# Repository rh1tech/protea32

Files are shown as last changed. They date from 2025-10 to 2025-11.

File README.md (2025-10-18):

# Protea

Protea is an open-source, feature-rich serial terminal and Wi-Fi modem PCB, designed in KiCad and released under the GNU General Public License (version 3 or later). Inspired by David Hansel's](https://github.com/dhansel) [VersaTerm](https://github.com/dhansel/VersaTerm) and [Richard Bettridge's](https://richardbettridge.com/) [RS232 Serial Wi-Fi Modem](https://github.com/TheOldNet/vintage-computer-wifi-modem), Protea combines modern connectivity with classic terminal functionality.

## Key Features

* **Plug-and-Play Operation**: simply connect a standard USB keyboard and an HDMI display—no additional host system or software required. Protea powers on instantly, requiring no boot-up sequence or shutdown procedure.
* **Universal Serial I/O**. Supports both RS232 and TTL (3.3 V or 5 V) serial levels. Choose from fixed presets or any custom baud rate between 50 and 921 600 baud. Full hardware (RTS/CTS) and software (XOn/XOff) flow control ensure reliable data transfer.
* **Comprehensive VT100 Emulation**. Full support for VT100 attributes—including bold, underline, blink, inverse, double width, and double height—and 16 ANSI colors. Advanced control-sequence compatibility passes VTTest for VT52/VT100/VT102 conformance.
* **PETSCII Mode**. Emulates the PETSCII character set and control codes used by the Commodore 64, complete with an authentic PETSCII bitmap font.
* **RP2040-Powered**. Built around the Raspberry Pi RP2040 microcontroller, Protea delivers instant-on performance and robust processing for terminal emulation.
* **Built-In Wi-Fi Modem**. Integrates an ESP8266EX module with on-board antenna, providing transparent serial-to-Wi-Fi bridging for telnet, web-based interfaces, or custom network protocols. Enables remote terminal sessions over local networks or the Internet.
* **Highly Configurable**. Customizable color palettes, and savable configuration profiles mean you can tailor Protea to any workflow. A built-in menu system allows on-the-fly adjustments without recompiling firmware.

Protea brings together the convenience of modern hardware with the nostalgia and versatility of vintage terminal interfaces—ideal for hobbyists, retro-computing enthusiasts, and embedded systems developers.

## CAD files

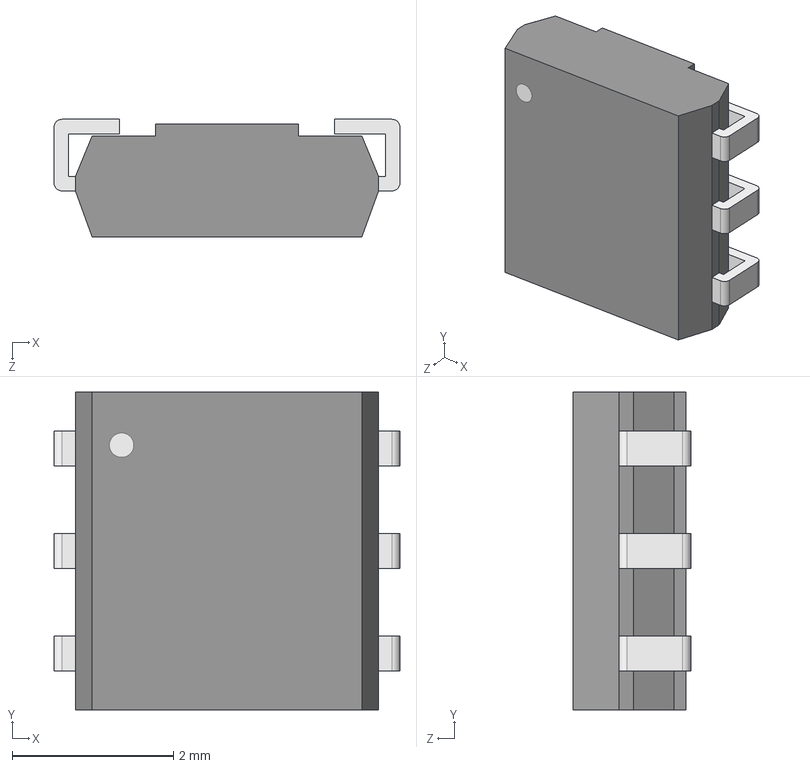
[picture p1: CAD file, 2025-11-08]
3D/DS2401P+.stp
4.29 x 3.94 x 1.46 mm

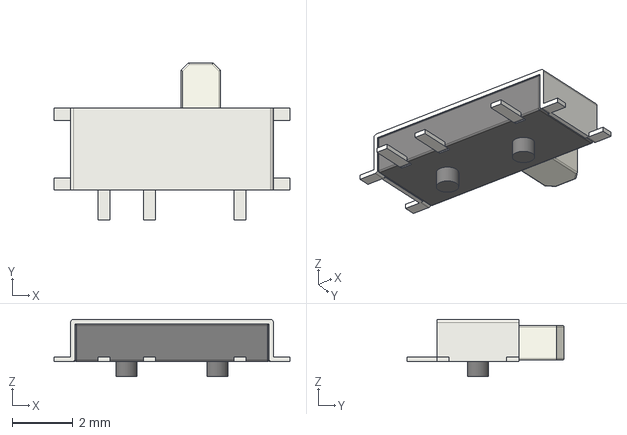
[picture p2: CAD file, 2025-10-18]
3D/SW_MSK12C02.step
7.80 x 5.20 x 1.90 mm

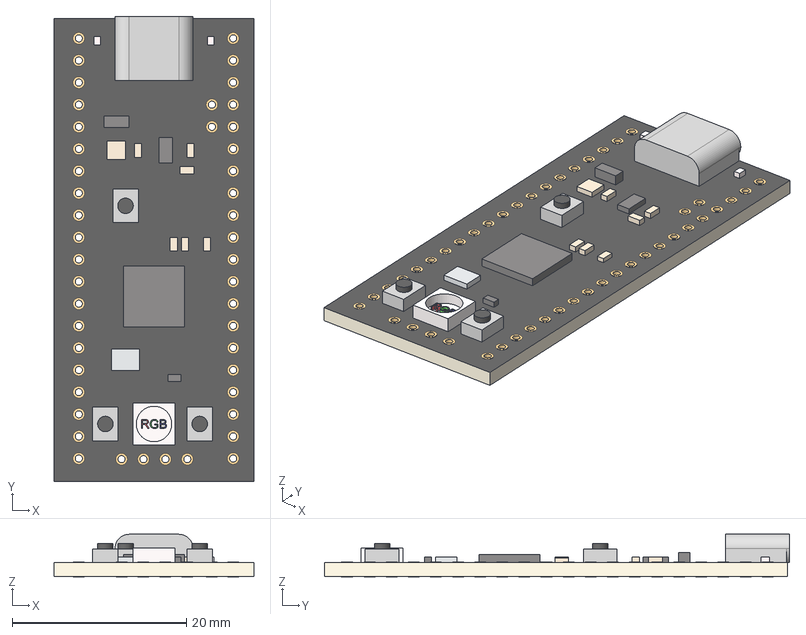
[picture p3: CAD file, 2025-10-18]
3D/PICO Clone-Black .step
22.9 x 53.3 x 4.88 mm

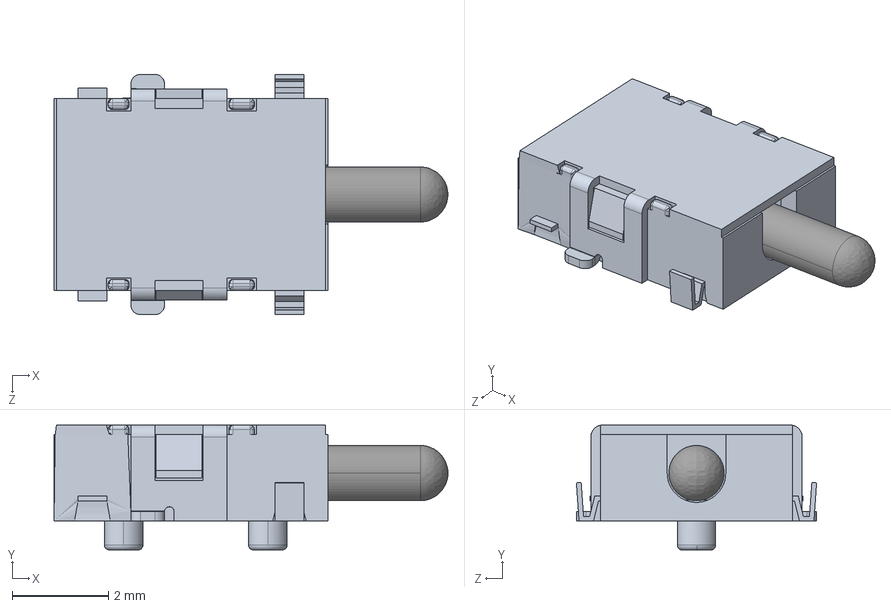
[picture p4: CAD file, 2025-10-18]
3D/SDS001R.stp
8.20 x 2.60 x 5.00 mm
SDS001R_PART1_1
SDS001R_PART2_3
SDS001R_PART2_2

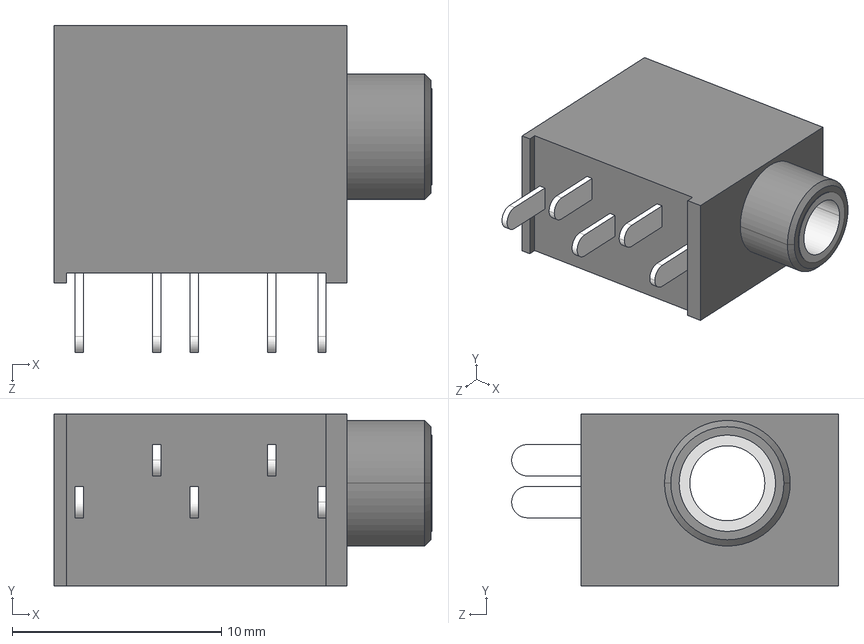
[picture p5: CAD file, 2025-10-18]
3D/SJ1-3535NG.stp
18.1 x 8.20 x 15.6 mm

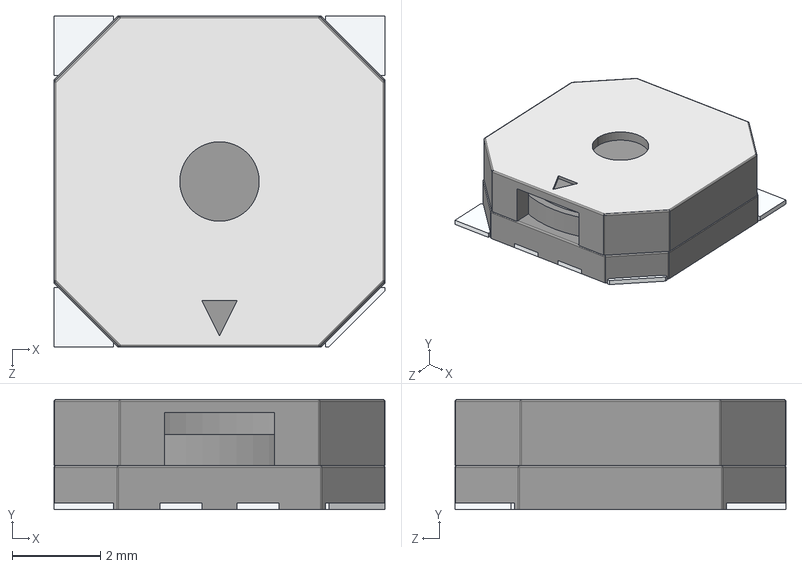
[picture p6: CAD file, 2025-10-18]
3D/CMT-7525-80-SMT-TR.stp
7.50 x 2.50 x 7.50 mm

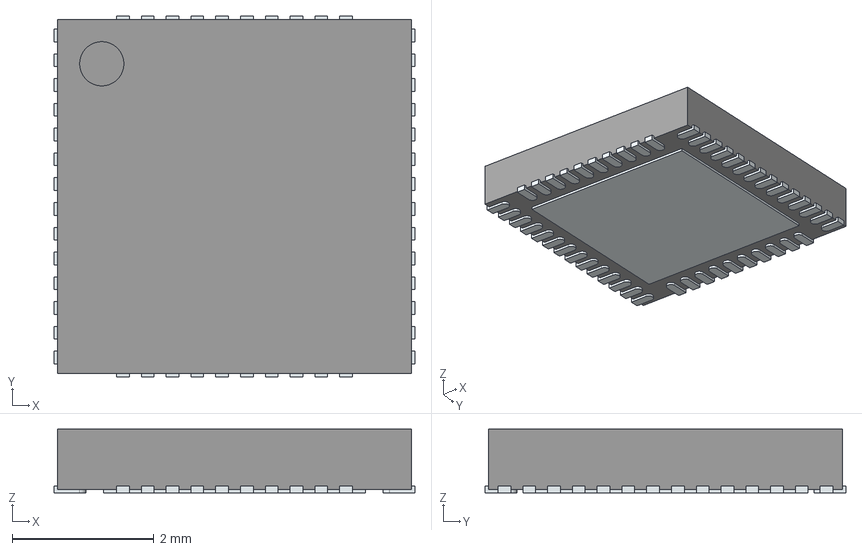
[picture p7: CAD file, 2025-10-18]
3D/ESP32-D0WD-V3.stp
5.10 x 5.10 x 0.9 mm
ThermalPin
PinsArrayLR
PinsArrayTB

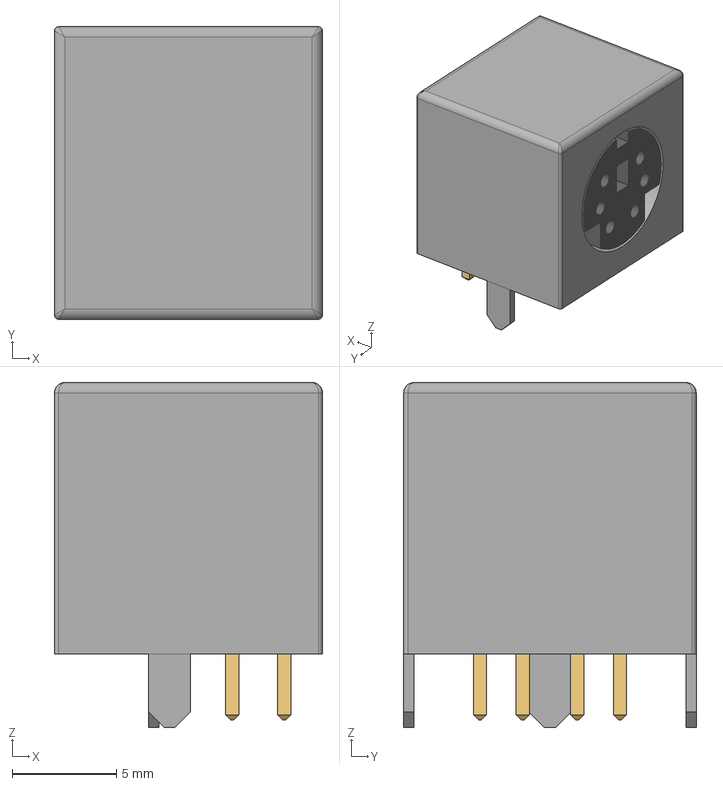
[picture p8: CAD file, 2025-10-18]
3D/Mini-DIN-6P.step
12.8 x 14.0 x 16.5 mm

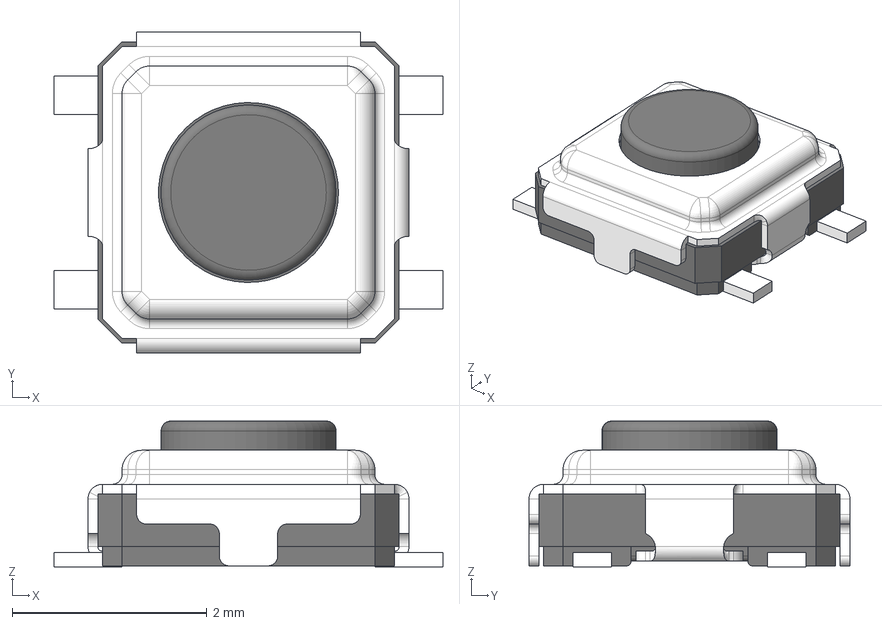
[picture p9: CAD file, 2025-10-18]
3D/Ts-1233_1.5.stp
4.00 x 3.30 x 1.50 mm

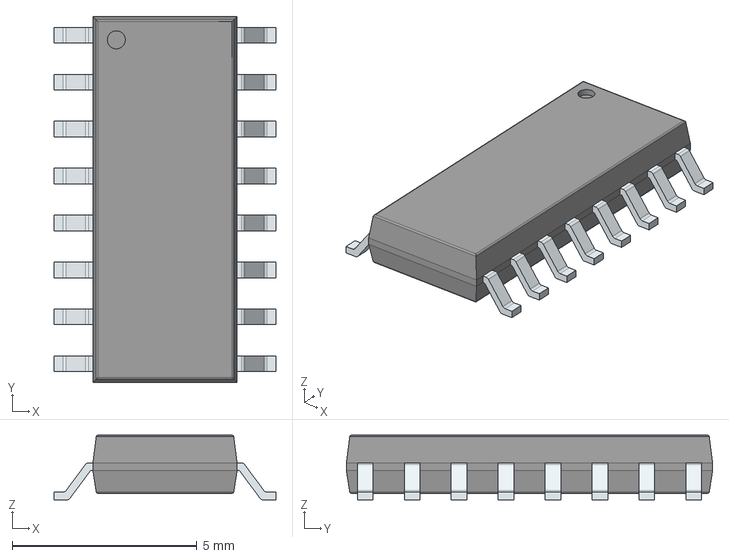
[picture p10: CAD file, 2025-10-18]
3D/MAX232CSE+.stp
6.00 x 9.90 x 1.75 mm
PinsArrayLR

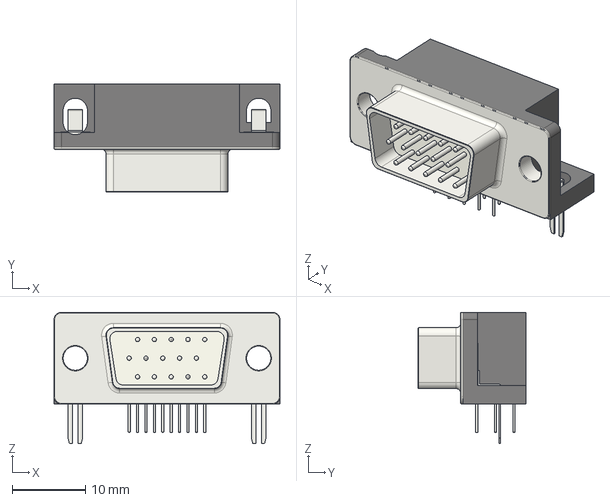
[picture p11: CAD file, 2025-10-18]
3D/DSUB-15-HD_Male_Horizontal_P2.29x1.98mm_EdgePinOffset3.03mm_Housed_MountingHolesOffset4.94mm.step
30.8 x 14.7 x 17.9 mm

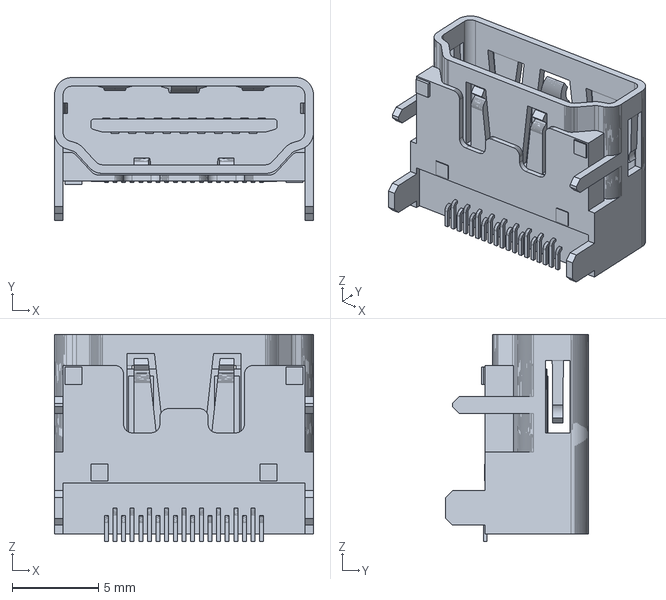
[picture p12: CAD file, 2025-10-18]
3D/HDMI.ipt.igs
15.0 x 8.28 x 12.0 mm

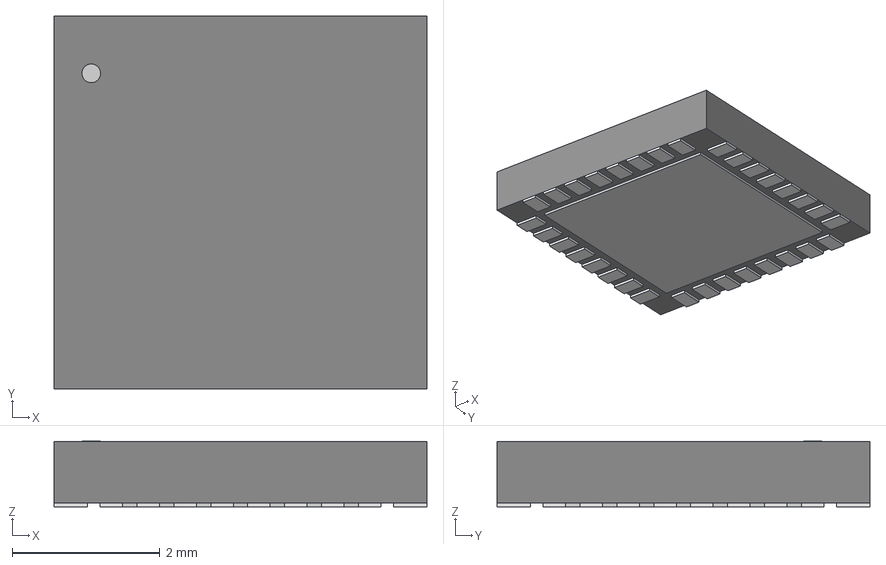
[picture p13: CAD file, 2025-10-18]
3D/ESP8266EX_EXP.step
5.05 x 5.05 x 0.892 mm

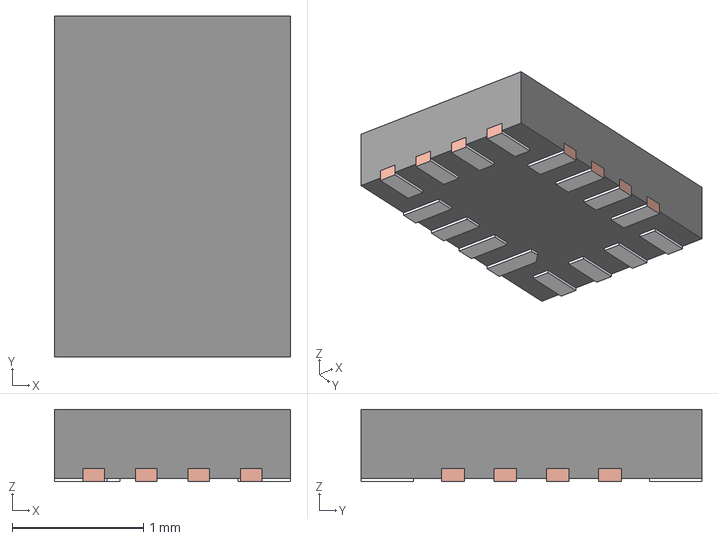
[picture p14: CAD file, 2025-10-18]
3D/RSV0016A.stp
1.80 x 2.60 x 0.55 mm
BODY-SON1
FRAME-RSV0016A

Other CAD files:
3D/DS05-127-2-04BK-SMT-TR.step
3D/W25Q128JVSIQ.stp
3D/soic-14.stp
3D/DS05-127-2-03BK-SMT-TR.step
3D/1TS003B.step
3D/3225 SMD Crystal Oscillator.STEP
3D/47571-0001.stp
3D/CUI_DEVICES_RCJ-013.step
3D/DS05-127-2-03BK-SMT-TR.stp
3D/DSUB-9_Female_Horizontal_P2.77x2.84mm_EdgePinOffset9.90mm_Housed_MountingHolesOffset11.32mm.step
3D/HRO_TYPE-C-31-M-12.step
3D/PJ320D.STEP
3D/SO-8_5.3x6.2mm_P1.27mm.step
3D/SOP-16_3.9x9.9mm_P1.27mm.step
3D/TS3USB221RSER.stp
3D/USB1035-GF-P-0-B-B.stp

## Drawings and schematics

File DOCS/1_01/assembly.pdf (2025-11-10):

U9 R²⁸ | D⁶ | R³ R²³ 1 | 2 | 3 | 4 | 5 | 6 1 | 2 | 3 | 4 | 5 | 6 ABCD | ABCD Date: 2025-11-08 KiCad E.D.A. 9.0.5 Size: A4 | Rev: 1.01

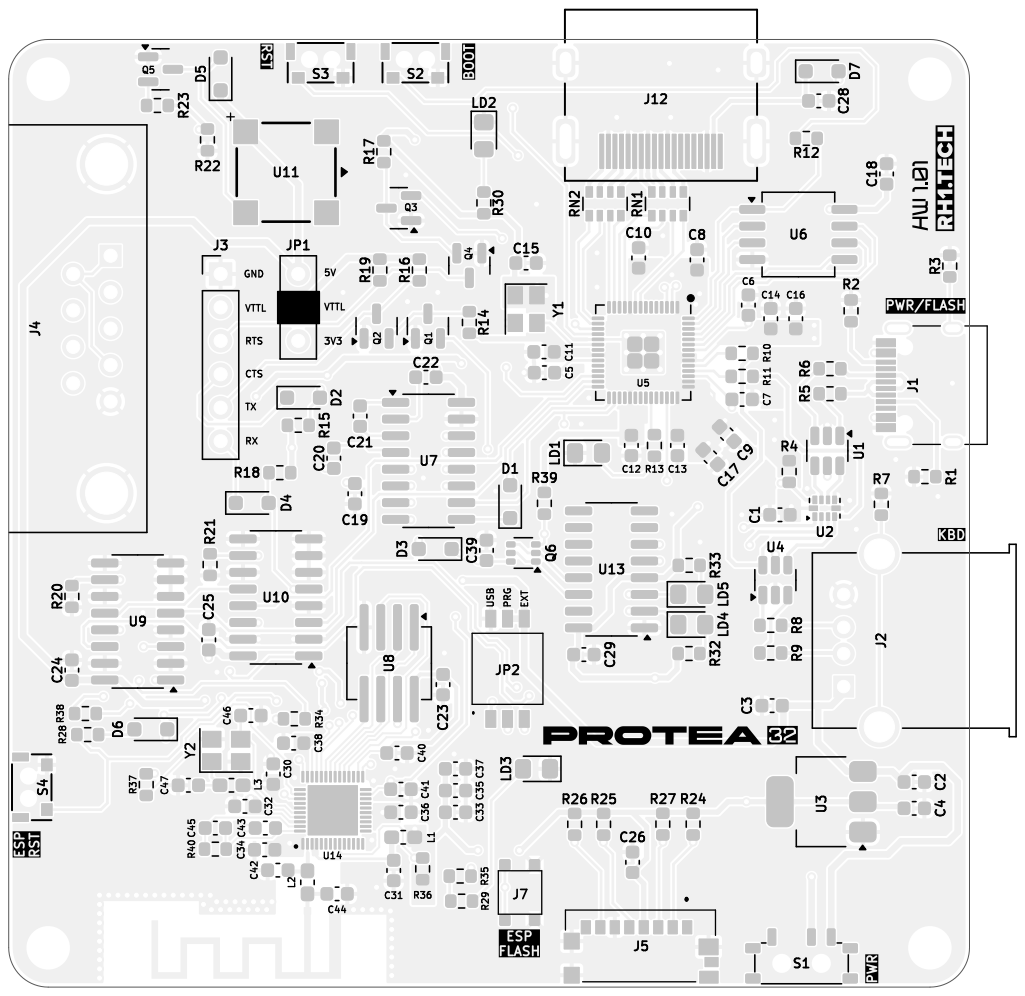
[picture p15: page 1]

https://github.com/rh1tech/protea Black And White TOP - Page 1/4

File: protea32.kicad_pcb Sheet: Black And White TOP Mikhail Matveev

1 | 2 | 3 | 4 | 5 | 6

A

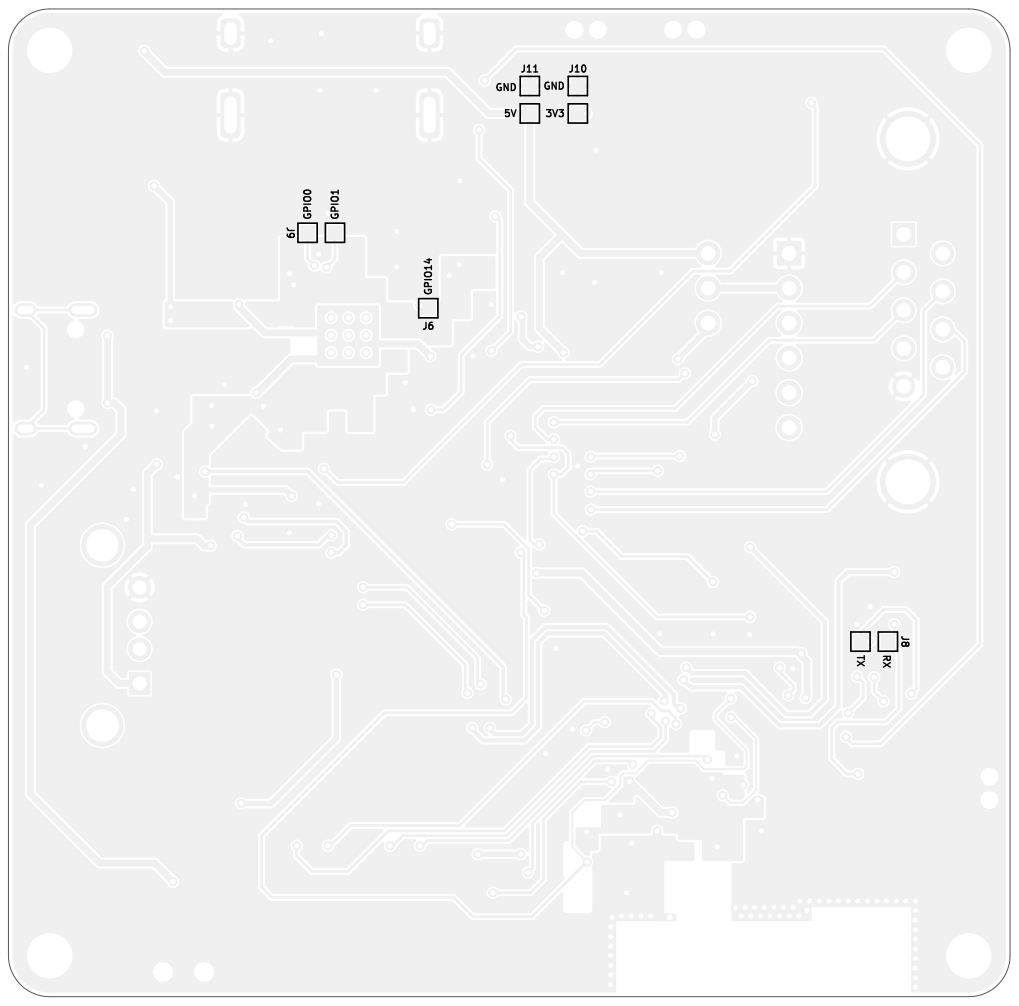
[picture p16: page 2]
TX GPIO⁰; 5V GPIO¹⁴; GND GPIO¹; RX GND; D Date: 2025-11-08 KiCad; E.D.A. 9.0.5 Size: A4; Rev: 1.01; Id: /1 Title: Protea32; File: protea32.kicad_pcb Sheet: Black; And; White; BOT Mikhail; Matveev; https://github.com/rh1tech/protea Black; BOT -; Page 2/4

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

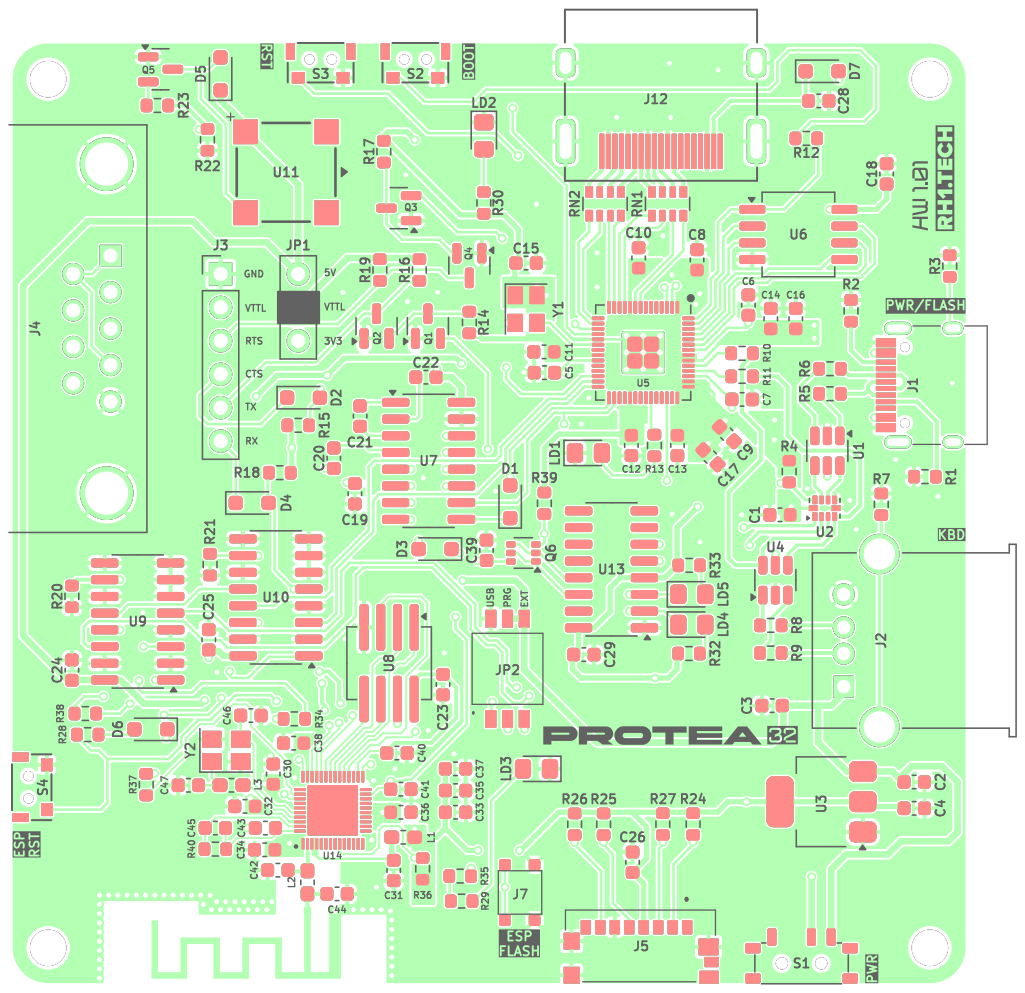
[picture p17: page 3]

1 | 2 | 3 | 4 | 5 | 6

A

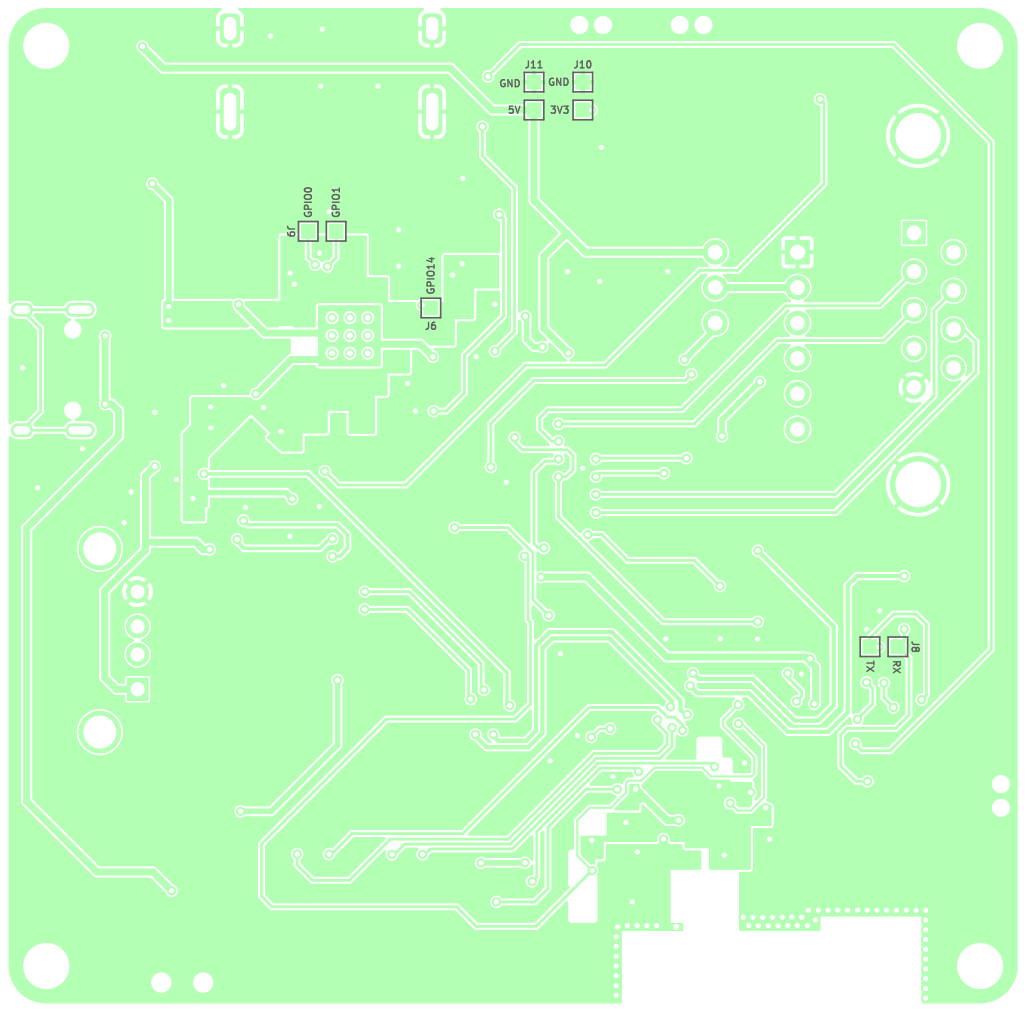
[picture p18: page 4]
TX GPIO⁰; 5V GPIO¹⁴; GND GPIO¹; RX GND; D Date: 2025-11-08 KiCad; E.D.A. 9.0.5 Size: A4; Rev: 1.01; Id: /1 Title: Protea32; File: protea32.kicad_pcb Sheet: Colored; BOT Mikhail; Matveev; https://github.com/rh1tech/protea Colored; BOT -; Page 4/4

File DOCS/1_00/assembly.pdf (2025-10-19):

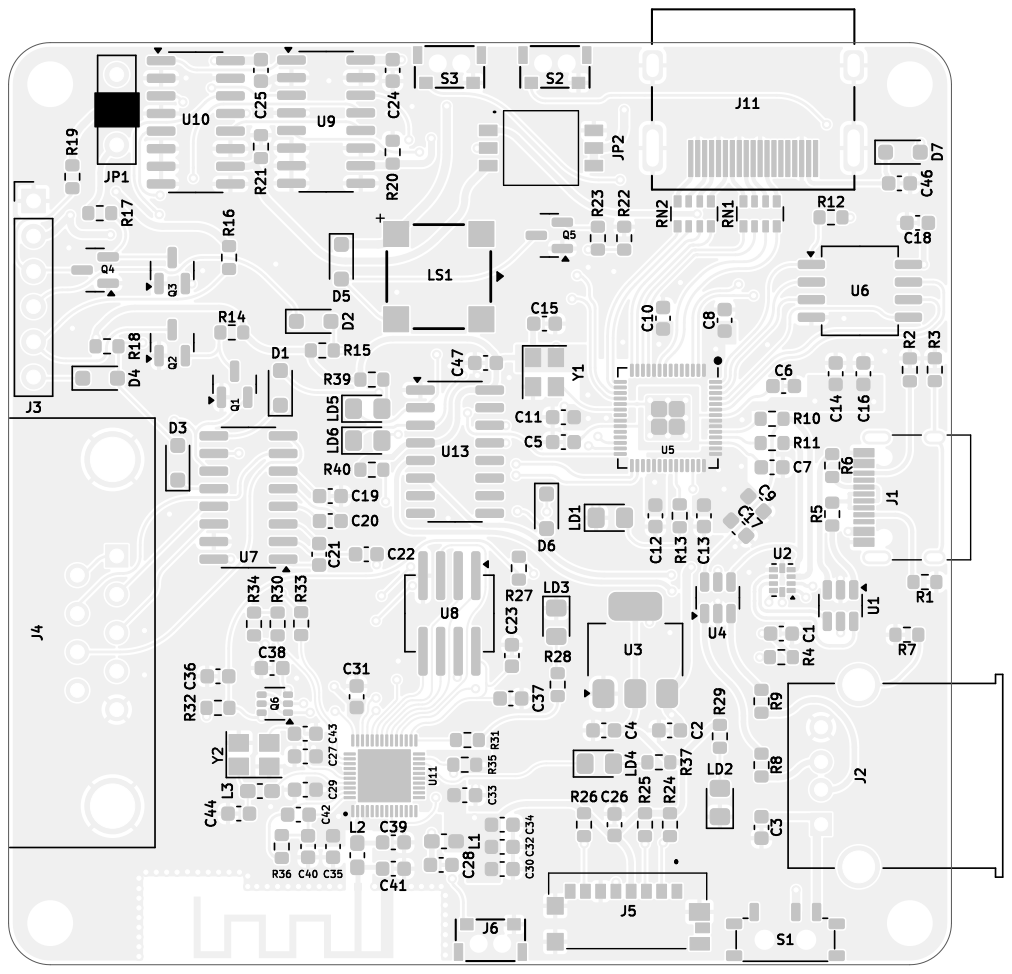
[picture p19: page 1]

https://github.com/xtremespb/frank Black And White TOP - Page 1/4

File: protea32.kicad_pcb Sheet: Black And White TOP Mikhail Matveev

A

A

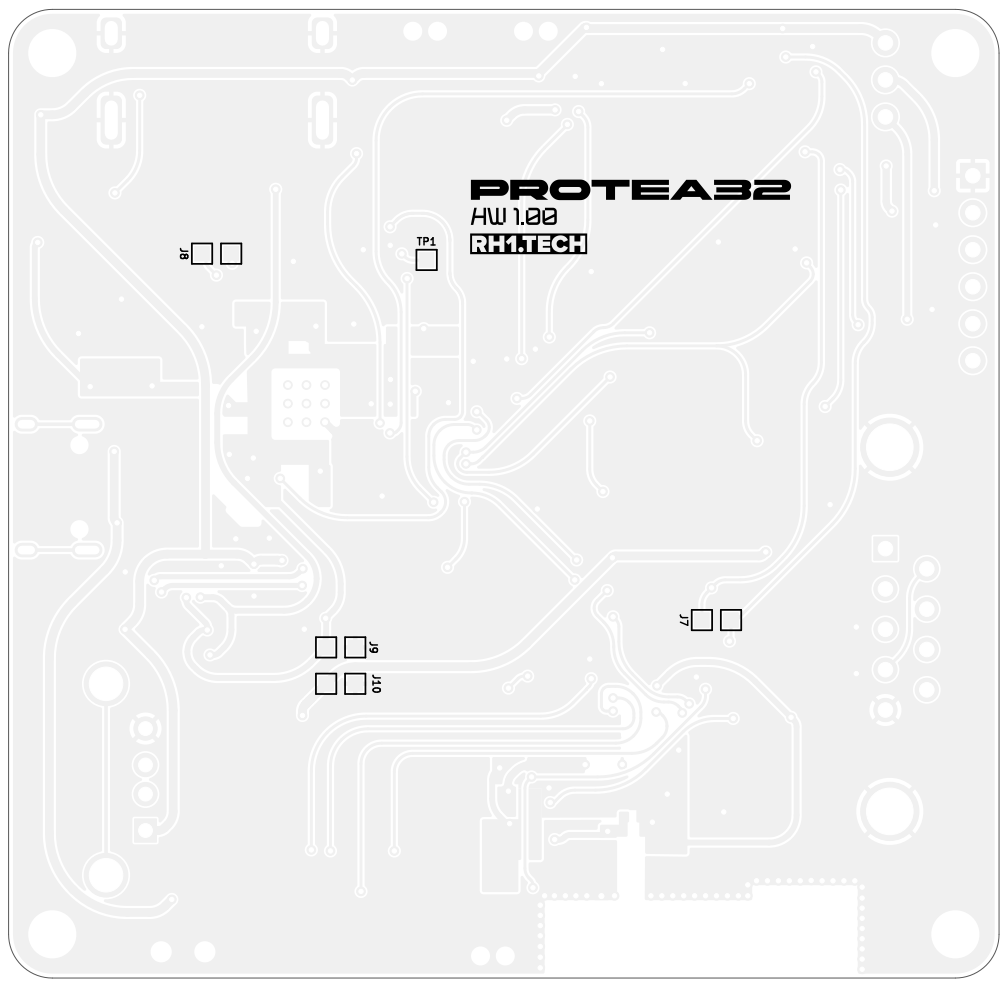
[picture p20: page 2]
D Date: 2025-10-19 KiCad; E.D.A. 9.0.5 Size: A4; Rev: 1.00; Id: /1 Title: Protea32; File: protea32.kicad_pcb Sheet: Black; And; White; BOT Mikhail; Matveev; https://github.com/xtremespb/frank Black; BOT -; Page 2/4

1 | 2 | 3 | 4 | 5 | 6 1 | 2 | 3 | 4 | 5 | 6 ABCD | ABCD Date: 2025-10-19 KiCad | E.D.A. 9.0.5 Size: A4 | Rev: 1.00

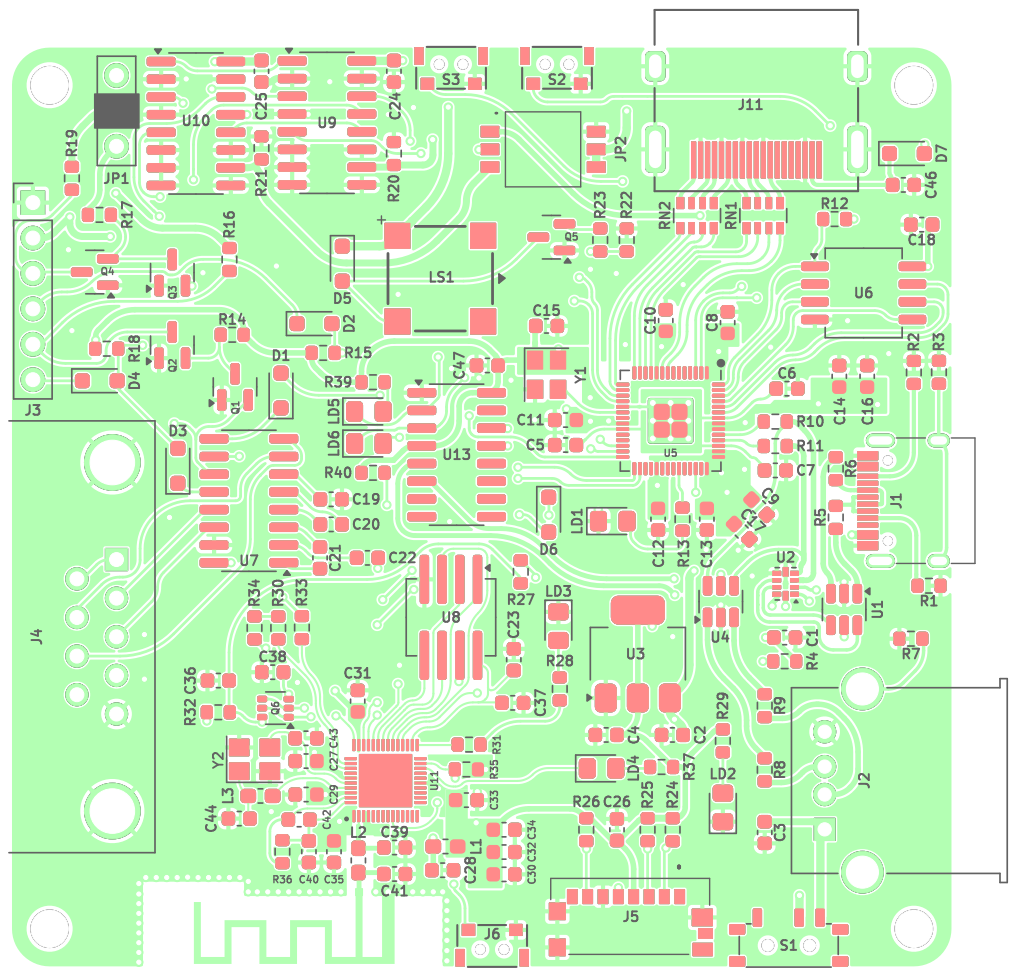
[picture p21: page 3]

A

A

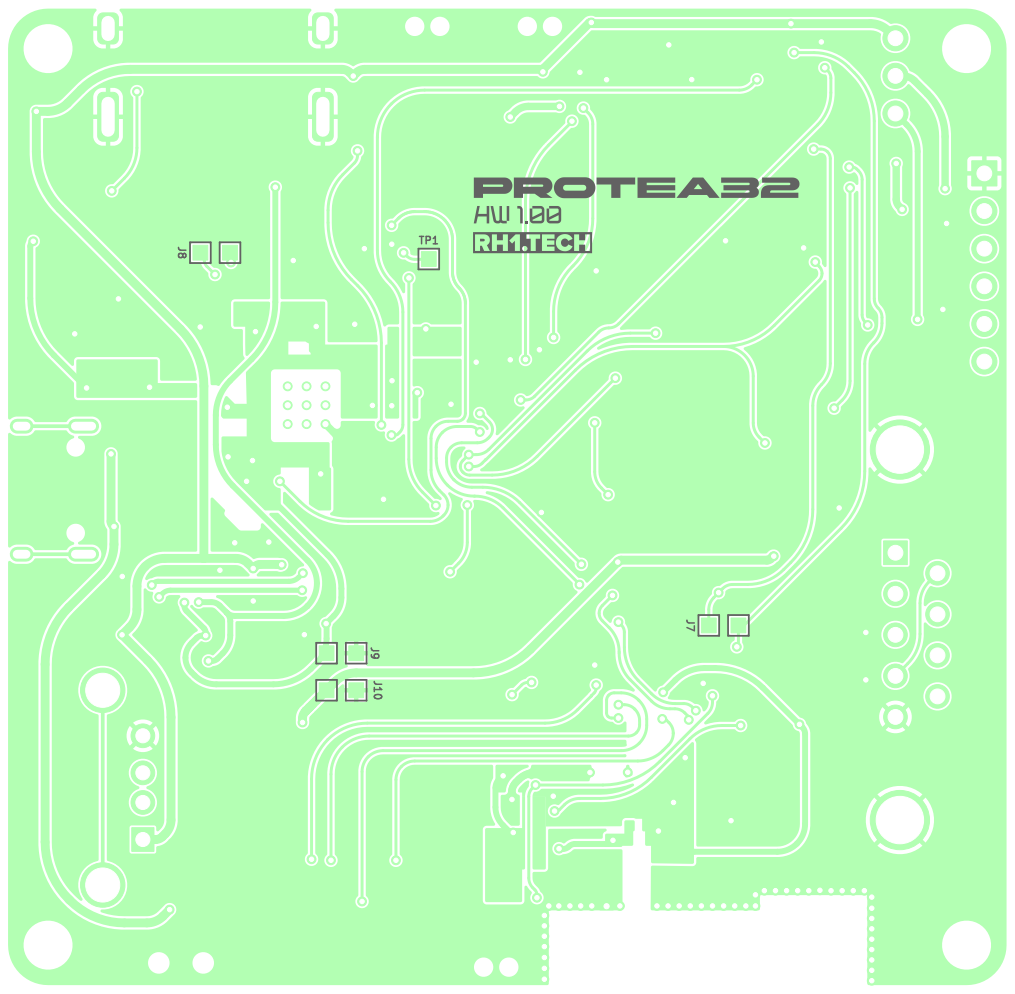
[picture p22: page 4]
D Date: 2025-10-19 KiCad; E.D.A. 9.0.5 Size: A4; Rev: 1.00; Id: /1 Title: Protea32; File: protea32.kicad_pcb Sheet: Colored; BOT Mikhail; Matveev; https://github.com/xtremespb/frank Colored; BOT -; Page 4/4

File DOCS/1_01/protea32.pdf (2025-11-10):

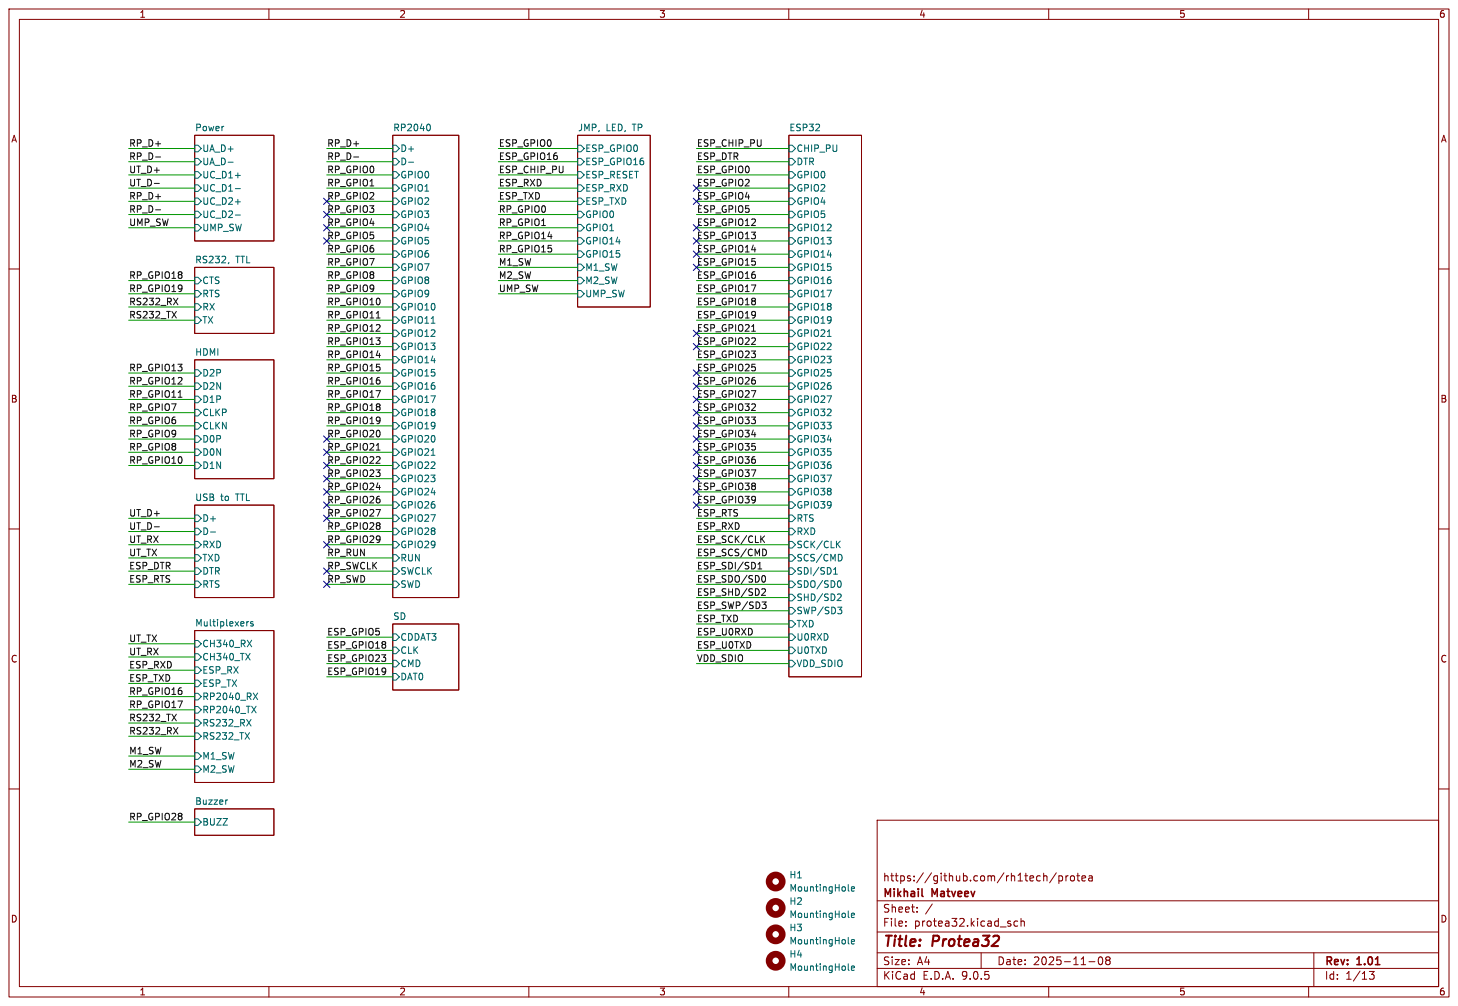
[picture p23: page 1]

TX RS232, TTL D+D- RXD
HDMI CTS RTS RX

SCK/CLK
SCS/CMD
SDI/SD1 SDO/SD0 SHD/SD2 SWP/SD3 TXD

https://github.com/rh1tech/protea

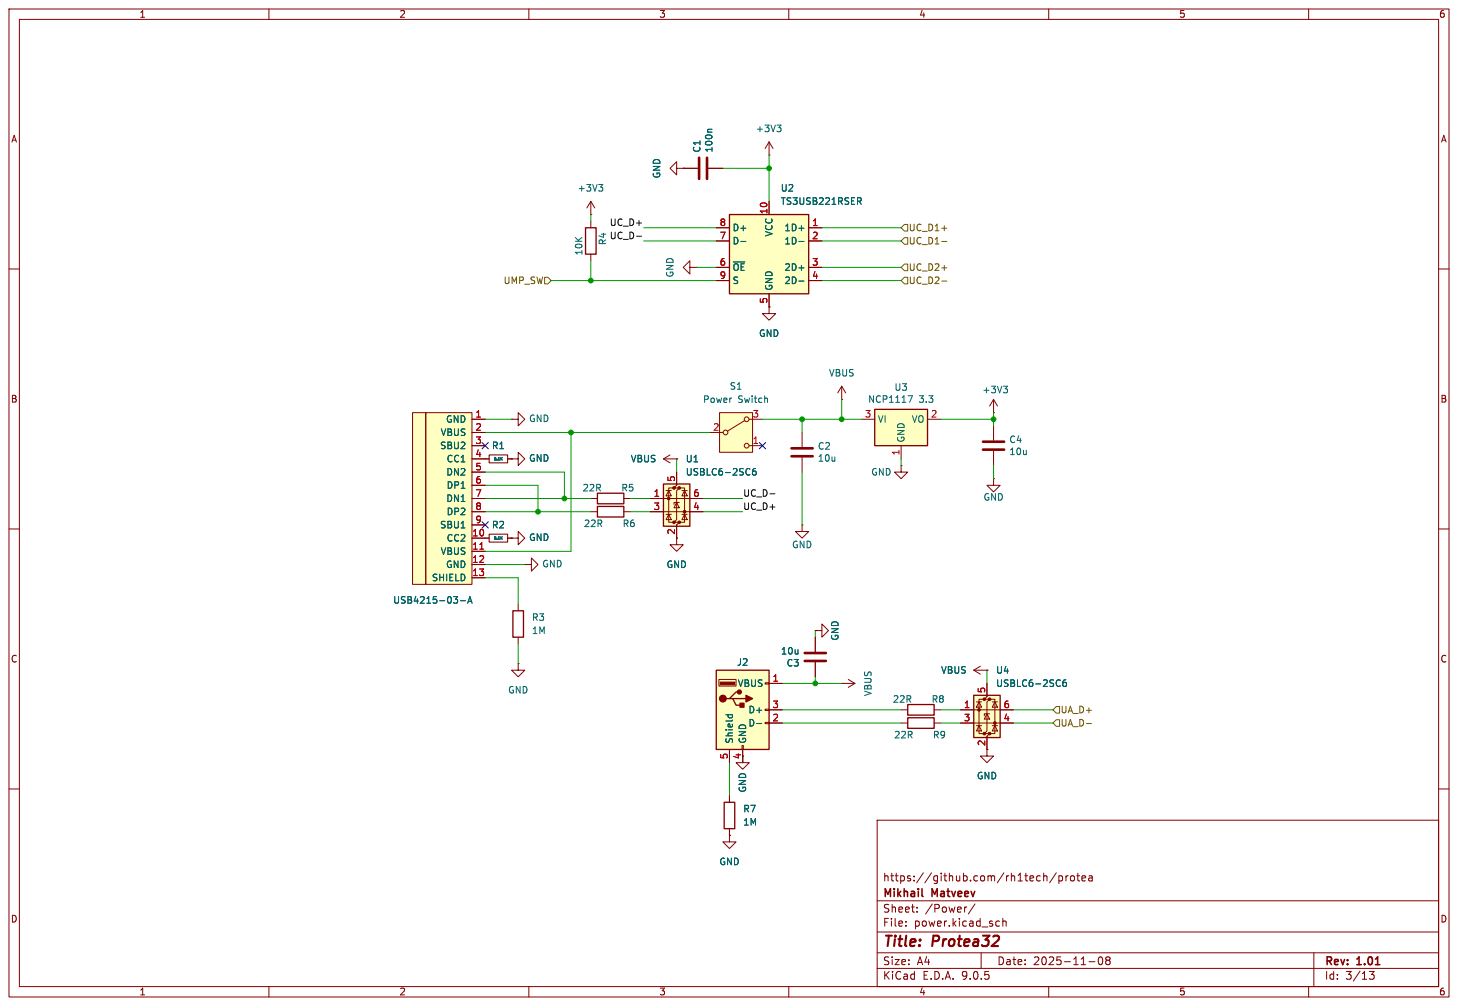
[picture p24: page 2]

https://github.com/rh1tech/protea GND

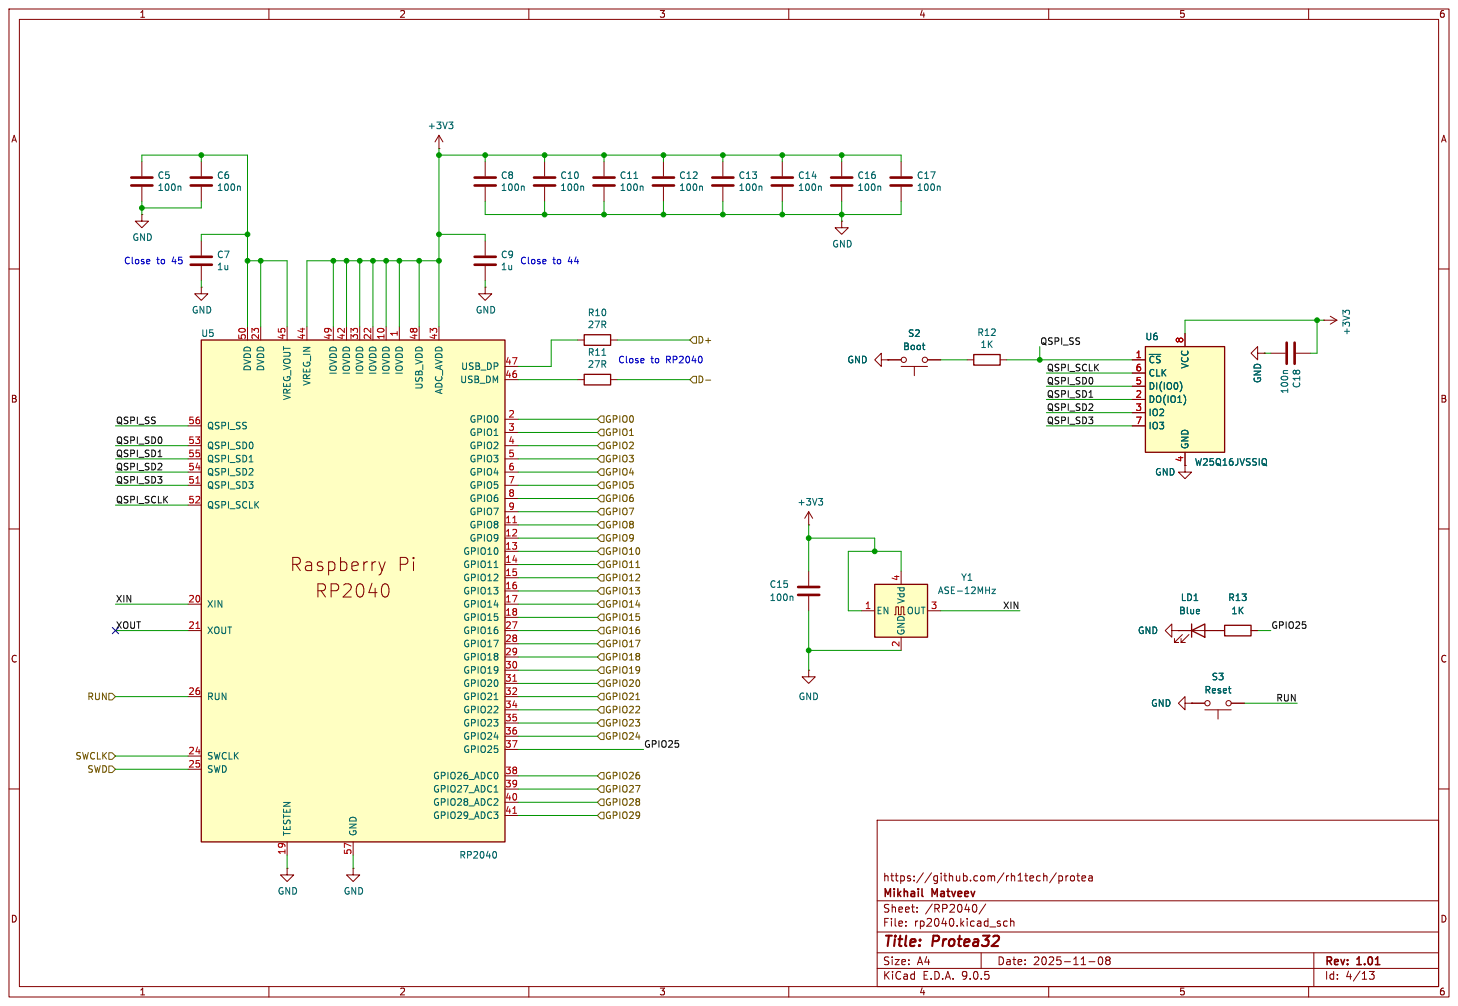
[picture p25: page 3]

4 U6 W25Q16JVSSIQ
~{CS} 1 CLK 6 DI(IO0) 5 DO(IO1) 2

https://github.com/rh1tech/protea

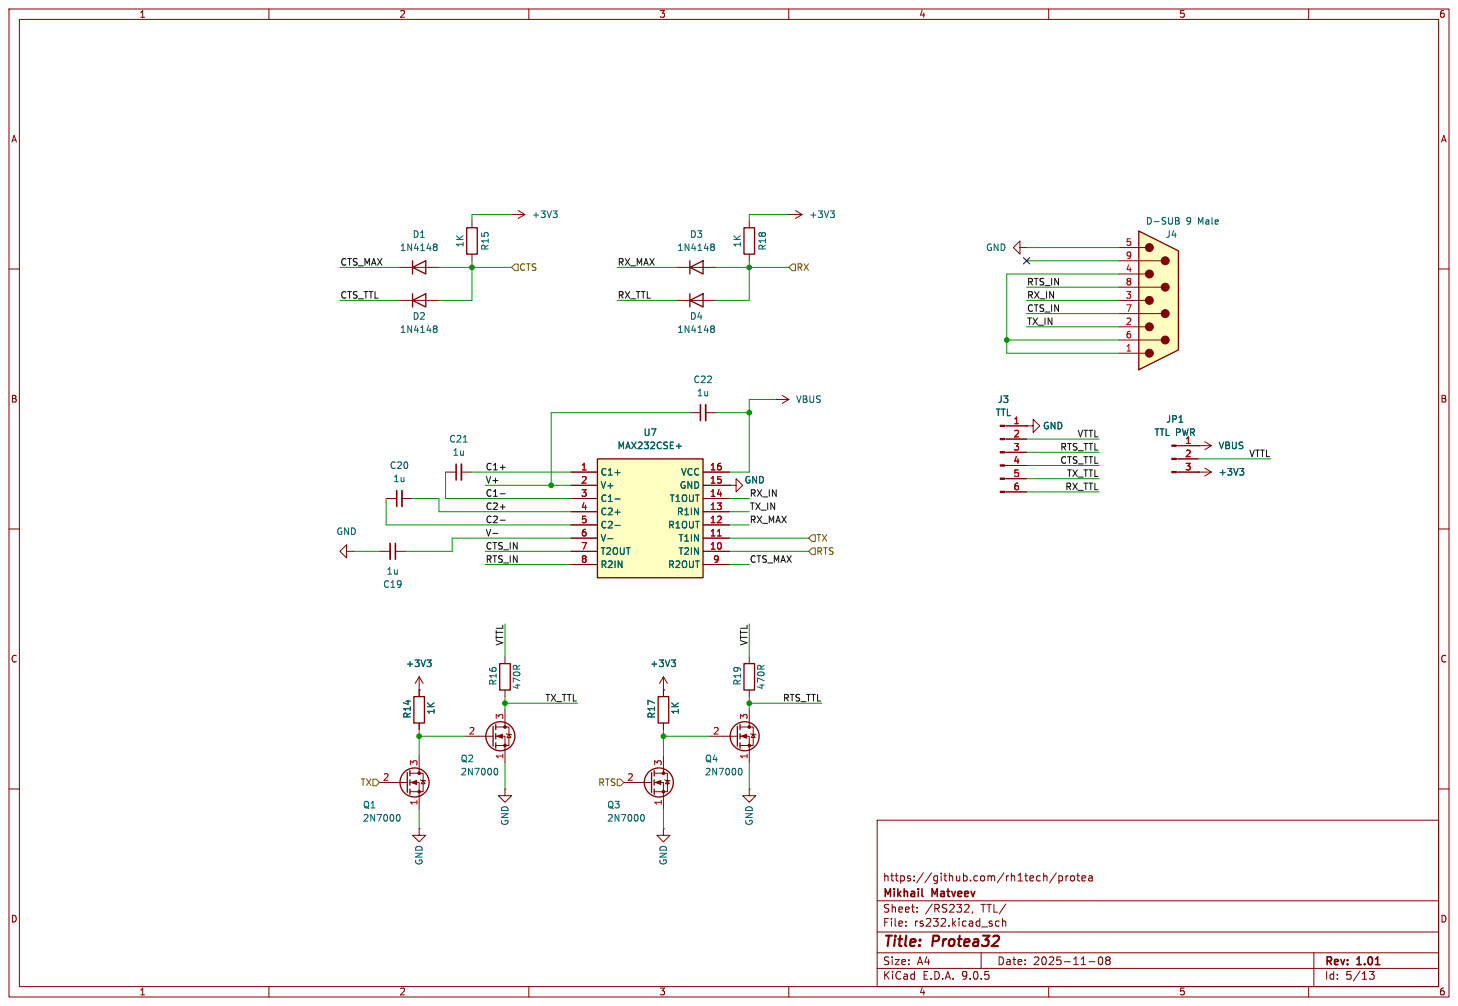
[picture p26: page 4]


https://github.com/rh1tech/protea


https://github.com/rh1tech/protea


https://github.com/rh1tech/protea C26 100n


https://github.com/rh1tech/protea GND
+3V3 GND


https://github.com/rh1tech/protea



https://github.com/xtremespb/frank SCK/CLK
SCS/CMD
SDI/SD1 SDO/SD0 SHD/SD2 SWP/SD3 VDD_SDIO


SHD/SD2 SDO/SD0 SCS/CMD
SWP/SD3 SDI/SD1 SCK/CLK

https://github.com/xtremespb/frank


https://github.com/xtremespb/frank

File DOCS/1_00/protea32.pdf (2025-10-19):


JMP, LED, TP D+D- RXD

RTS USB to TTL D2P D2N
RP_GPIO8 RP_GPIO10 UT_TX

https://github.com/xtremespb/frank CH340_RX CH340_TX
ESP_TX M1_SW

SCK/CLK
SCS/CMD
SDI/SD1 SDO/SD0 SHD/SD2 SWP/SD3 TXD



S3 Reset LD1 Blue S2 Boot GND

https://github.com/xtremespb/frank



https://github.com/xtremespb/frank


https://github.com/xtremespb/frank


https://github.com/xtremespb/frank GND GND GND


https://github.com/xtremespb/frank GND


SCK/CLK
SCS/CMD
SDI/SD1 SDO/SD0 SHD/SD2 SWP/SD3 VDD_SDIO

https://github.com/xtremespb/frank GPIO16 GPIO17 SDI/SD1 SDO/SD0 SHD/SD2 SWP/SD3 VDD_SDIO


SHD/SD2 SDO/SD0 SCS/CMD
SWP/SD3 SDI/SD1 SCK/CLK

https://github.com/xtremespb/frank


https://github.com/xtremespb/frank


https://github.com/xtremespb/frank


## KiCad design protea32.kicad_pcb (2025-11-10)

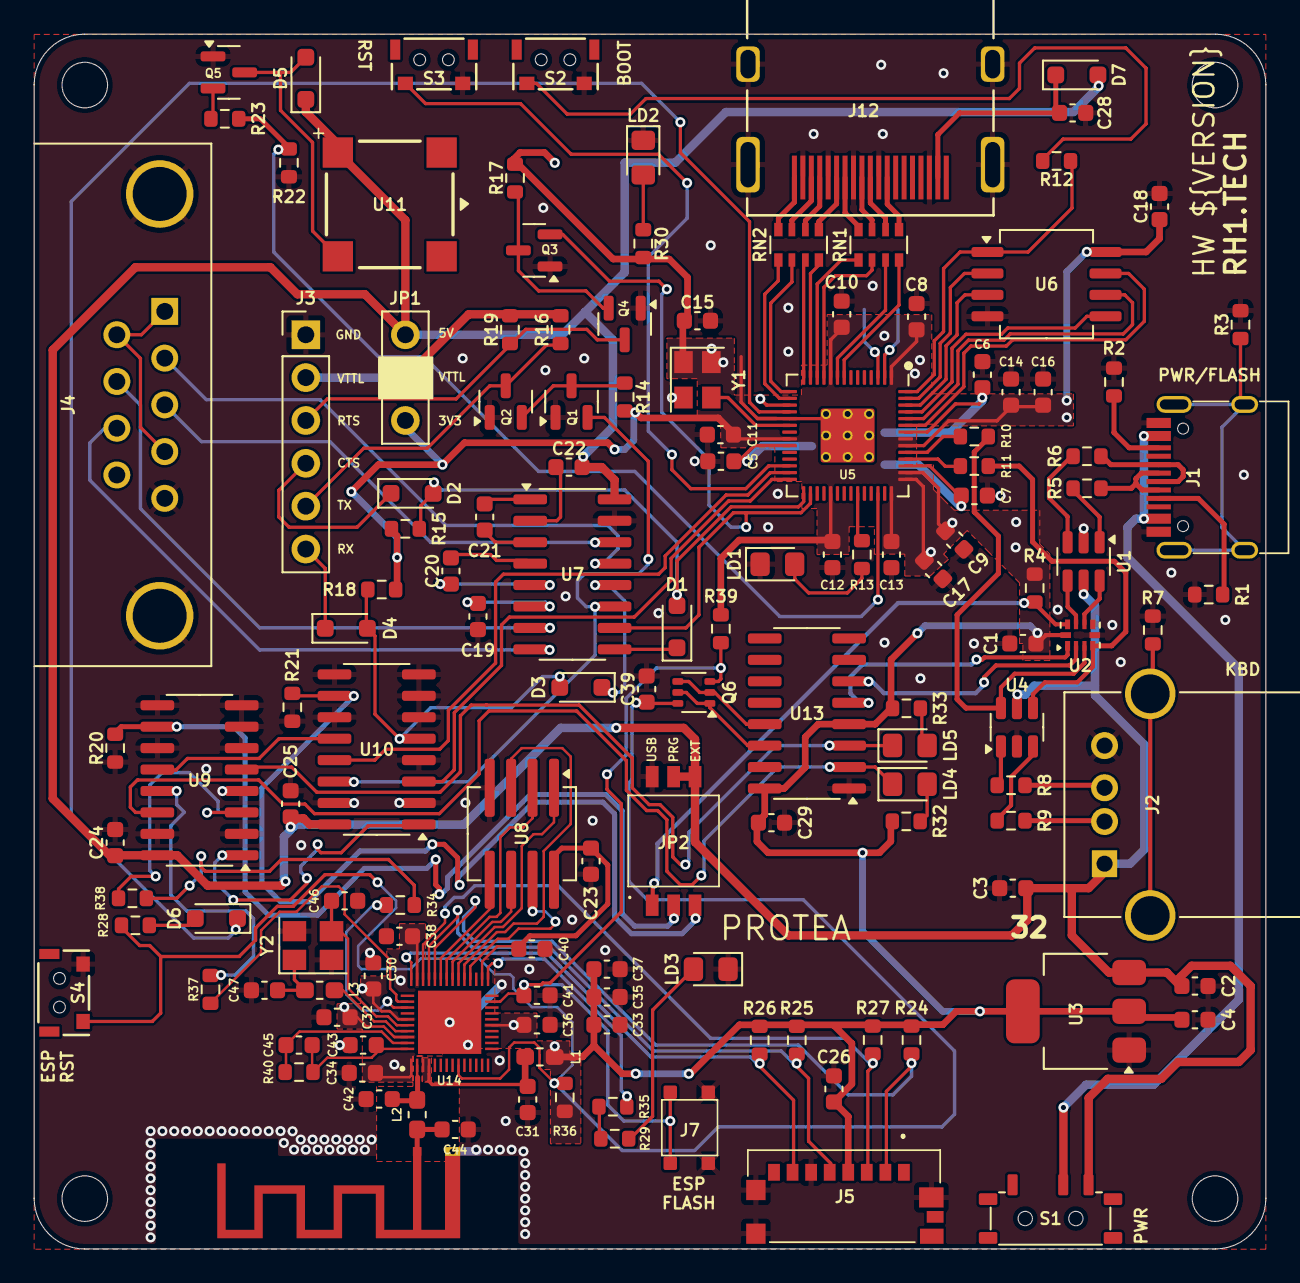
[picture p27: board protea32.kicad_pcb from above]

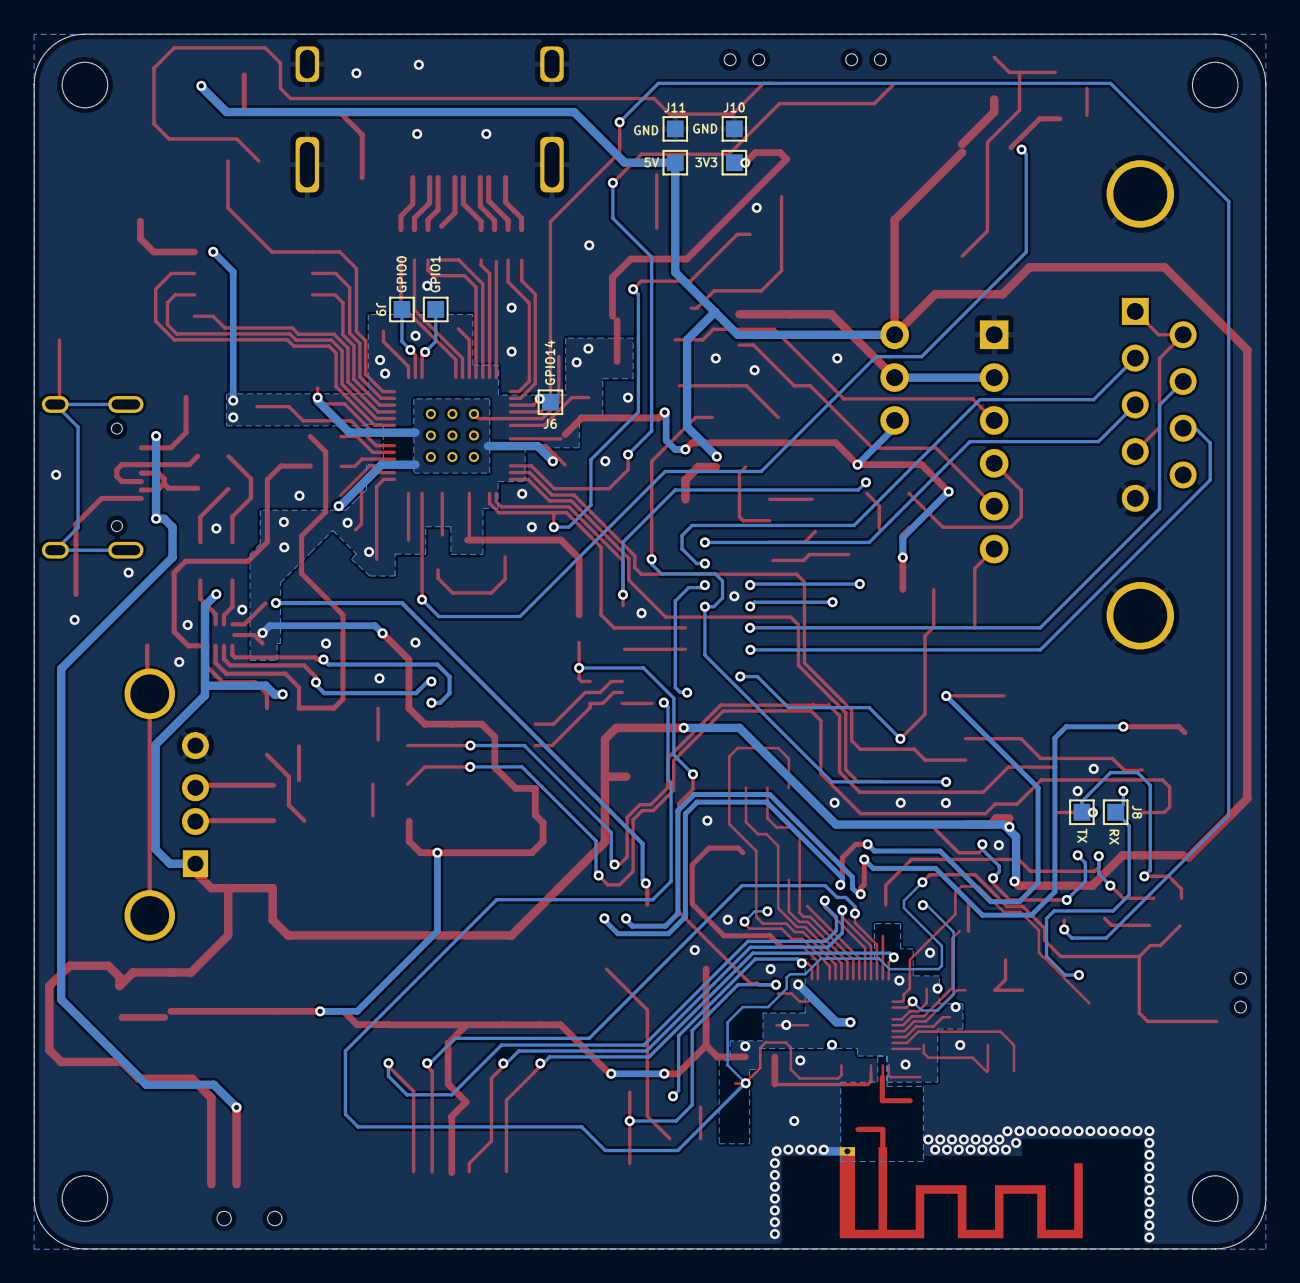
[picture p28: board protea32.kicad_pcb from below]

Board: 2 copper layers, 73.0 x 72.0 mm, 146 parts (5 on the bottom side), 128 nets.

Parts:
AE1: Antenna_Shield; Antenna (2.4GHz)
C1, C5, C6, C8, C10, C11, C12, C13, C14, C15, C16, C17, C18, C23, C24, C25, C26, C28, C29, C31, C33, C34, C36, C38: 100n; Capacitor (0603, S)
C2, C3, C4, C35: 10u; Capacitor (0603, S)
C7, C9, C19, C20, C21, C22, C30, C37, C40: 1u; Capacitor (0603, S)
C32: 100p; Capacitor (0603, S)
C39, C41: 1n; Capacitor (0603, S)
C42: 1.5pF; Capacitor (0603, S)
C43: 10n; Capacitor (0603, S)
C44: 2.4pF; Capacitor (0603, S)
C45: 3.3n; Capacitor (0603, S)
C46, C47: 12p; Capacitor (0603, S)
D1, D2, D3, D4, D5, D6: 1N4148; Diode (SOD-323)
D7: 1N5819WS; Diode (SOD-323)
H1, H2, H3, H4: MountingHole; Mounting Hole (2.7mm)
J1: USB4215-03-A; USB Type C
J2: 676430910; USB Type A (single)
J3: TTL; PinHeader_1x06_P2.54mm_Vertical
J4: D-SUB 9 Male; D-SUB (9 pin, male, top mount)
J5: 0475710001; MicroSD (SMD, short)
J6: Defaults; Test Point (1mm x 1)
J7: Flash; Button (SMD, 3x3mm, 1-1)
J8, J9, J10, J11: Test Points (1mm x 2)
J12: DC3RX19JA2; HDMI (female)
JP1: TTL PWR; PinHeader_1x03_P2.54mm_Vertical
JP2: Main Jumpers; DS05127203BKSMTTR
L1: 2nH; Inductor (0603 1.05x0.95)
L2: 2.7nH/0R; Inductor (0603 1.05x0.95)
L3: 24nH/0R; Inductor (0603 1.05x0.95)
LD1, LD3: Blue; LED (0805)
LD2: Green; LED (0805)
LD4, LD5: Orange; LED (0805)
Q1, Q2, Q3, Q4, Q5: 2N7000; SOT-23
Q6: UMH3N; SOT-363
R1, R2: 5.1K; Resistor (0603, S)
R3, R7: 1M; Resistor (0603, S)
R4, R20, R21, R22, R24, R25, R26, R27, R36, R39: 10K; Resistor (0603, S)
R5, R6, R8, R9: 22R; Resistor (0603, S)
R10, R11: 27R; Resistor (0603, S)
R12, R13, R14, R15, R17, R18, R30: 1K; Resistor (0603, S)
R16, R19, R29: 470R; Resistor (0603, S)
R23: 100R; Resistor (0603, S)
R28: 200R; Resistor (0603, S)
R32, R33: 1.5K; Resistor (0603, S)
R34: 499R; Resistor (0603, S)
R35: 0R; Resistor (0603, S)
R37, R38: 330R; Resistor (0603, S)
R40: 20K; Resistor (0603, S)
RN1, RN2: 270R; Resistor Array (4x0603)
S1: Power Switch; Switch (MSK12C02)
S2: Boot; TACT-SIDE-4623
S3: Reset; TACT-SIDE-4623
S4: ESP RST; TACT-SIDE-4623
U1, U4: USBLC6-2SC6; SOT-23-6
U2: TS3USB221RSER; UQFN-10
U3: NCP1117 3.3; SOT-223
U5: RP2040; QFN 56
U6: W25Q16JVSSIQ; SOIC-8
U7: MAX232CSE+; SOP-16
U8: W25Q32JVSIQ; SOIC-8 (Longer)
U9, U10: 74HC4052D; SOP-16
U11: CMT-7525-80-SMT-TR; CMT752580SMTTR
U13: CH340C; SOP-16
U14: ESP32-D0WD-V3; QFN35P500X500X90-49N-D
Y1: ASE-12MHz; Crystal (3225, active)
Y2: 40MHz; Crystal (3225)

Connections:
+3.3VP: C31.1, L1.2, U14.3 (VDD3P3_1), U14.4 (VDD3P3_2)
+3V3: C1.2, C4.1, C8.1, C9.1, C10.1, C11.1, C12.1, C13.1, C14.1, C15.1, C16.1, C17.1, C18.1, C26.2, C29.1, C30.1, C32.1, C33.1, C34.1, C35.1, C36.1, C37.1, C38.1, J5.P4 (VDD), J10.2, JP1.3, L1.1, R4.1, R14.2, R15.2, R17.2, R18.2, R24.2, R25.2, R26.2, R27.2, R30.2, R32.2, R33.1, R36.2, R39.2, U2.10 (VCC), U3.2 (VO), U5.1 (IOVDD), U5.10 (IOVDD), U5.22 (IOVDD), U5.33 (IOVDD), U5.42 (IOVDD), U5.43 (ADC_AVDD), U5.44 (VREG_IN), U5.48 (USB_VDD), U5.49 (IOVDD), U6.8 (VCC), U13.4 (3V), U13.16 (VCC), U14.1 (VDDA_1), U14.19 (VDD3P3_RTC), U14.37 (VDD3P3_CPU), U14.43 (VDDA_2), U14.46 (VDDA_3), Y1.1 (EN), Y1.4 (Vdd)
/ESP32/ANT: AE1.1 (A), C44.1, L2.1
/ESP32/CAP1: C43.1, C45.1, R40.2, U14.48 (CAP1)
/ESP32/CAP2: C45.2, R40.1, U14.47 (CAP2)
/ESP32/LNA_IN: C42.1, L2.2, U14.2 (LNA_IN)
/ESP32/XTAL_N: C46.1, U14.44 (XTAL_N), Y2.3
/ESP32/XTAL_P: L3.1, U14.45 (XTAL_P)
/ESP_CHIP_PU: C39.1, Q6.6 (C1), R28.1, R36.1, S4.1, U14.9 (CHIP_PU)
/ESP_DTR: Q6.2 (B1), Q6.4 (E2), U13.13 (DTR)
/ESP_GPIO0: C41.1, J7.2, Q6.3 (C2), R39.1, U14.23 (GPIO0)
/ESP_GPIO5: J5.P2 (CD/DAT3), R24.1, U14.34 (GPIO5)
/ESP_GPIO16: R29.1, R35.2
/ESP_GPIO18: J5.P5 (CLK), R25.1, U14.35 (GPIO18)
/ESP_GPIO19: J5.P7 (DAT0), R26.1, U14.38 (GPIO19)
/ESP_GPIO23: J5.P3 (CMD), R27.1, U14.36 (GPIO23)
/ESP_RTS: Q6.1 (E1), Q6.5 (B2), U13.14 (RTS)
/ESP_RXD: J8.1, R37.1, U9.13 (1Z)
/ESP_SCK/CLK: U8.6 (CLK), U14.31 (SD_CLK)
/ESP_SCS/CMD: U8.1 (~CS), U14.30 (SD_CMD)
/ESP_SDI/SD1: U8.5 (DI(IO0)), U14.33 (SD_DATA_1)
/ESP_SDO/SD0: U8.2 (DO(IO1)), U14.32 (SD_DATA_0)
/ESP_SHD/SD2: U8.7 (IO3), U14.28 (SD_DATA_2)
/ESP_SWP/SD3: U8.3 (IO2), U14.29 (SD_DATA_3)
/ESP_TXD: J8.2, R38.1, U9.3 (2Z)
/ESP_U0RXD: R37.2, U14.40 (U0RXD)
/ESP_U0TXD: R34.2, R38.2
/M1_SW: JP2.2, R20.2, U9.10 (S0)
/M2_SW: JP2.3, R21.2, U10.10 (S0)
/Multiplexers/MP_RX: U9.12 (1Y0), U10.12 (1Y0)
/Multiplexers/MP_TX: U9.1 (2Y0), U10.1 (2Y0)
/Power/UC_D+: U1.4 (I/O2), U2.8 (D+)
/Power/UC_D-: U1.6 (I/O1), U2.7 (D-)
/RP2040/GPIO25: R13.2, U5.37 (GPIO25)
/RP2040/QSPI_SCLK: U5.52 (QSPI_SCLK), U6.6 (CLK)
/RP2040/QSPI_SD0: U5.53 (QSPI_SD0), U6.5 (DI(IO0))
/RP2040/QSPI_SD1: U5.55 (QSPI_SD1), U6.2 (DO(IO1))
/RP2040/QSPI_SD2: U5.54 (QSPI_SD2), U6.3 (IO2)
/RP2040/QSPI_SD3: U5.51 (QSPI_SD3), U6.7 (IO3)
/RP2040/QSPI_SS: R12.1, U5.56 (QSPI_SS), U6.1 (~CS)
/RP2040/XIN: U5.20 (XIN), Y1.3 (OUT)
/RP_D+: R10.1, U2.3 (2D+), U4.6 (I/O1)
/RP_D-: R11.1, U2.4 (2D-), U4.4 (I/O2)
/RP_GPIO0: J9.1, U5.2 (GPIO0)
/RP_GPIO1: J9.2, U5.3 (GPIO1)
/RP_GPIO6: RN1.4 (R4.1), U5.8 (GPIO6)
/RP_GPIO7: RN1.3 (R3.1), U5.9 (GPIO7)
/RP_GPIO8: RN1.2 (R2.1), U5.11 (GPIO8)
/RP_GPIO9: RN1.1 (R1.1), U5.12 (GPIO9)
/RP_GPIO10: RN2.4 (R4.1), U5.13 (GPIO10)
/RP_GPIO11: RN2.3 (R3.1), U5.14 (GPIO11)
/RP_GPIO12: RN2.2 (R2.1), U5.15 (GPIO12)
/RP_GPIO13: RN2.1 (R1.1), U5.16 (GPIO13)
/RP_GPIO14: J6.1, U5.17 (GPIO14)
/RP_GPIO15: D6.1 (K), U5.18 (GPIO15)
/RP_GPIO16: U5.27 (GPIO16), U10.13 (1Z)
/RP_GPIO17: U5.28 (GPIO17), U10.3 (2Z)
/RP_GPIO18: D1.2 (A), D2.2 (A), R15.1, U5.29 (GPIO18)
/RP_GPIO19: Q3.2 (G), U5.30 (GPIO19), U7.10 (T2IN)
/RP_GPIO28: R22.2, R23.2, U5.40 (GPIO28_ADC2)
/RP_RUN: S3.1, U5.26 (RUN)
/RS232, TTL/C1+: C21.2, U7.1 (C1+)
/RS232, TTL/C1-: C21.1, U7.3 (C1-)
/RS232, TTL/C2+: C20.2, U7.4 (C2+)
/RS232, TTL/C2-: C20.1, U7.5 (C2-)
/RS232, TTL/CTS_IN: J4.7, U7.7 (T2OUT)
/RS232, TTL/CTS_MAX: D1.1 (K), U7.9 (R2OUT)
/RS232, TTL/CTS_TTL: D2.1 (K), J3.4
/RS232, TTL/RTS_IN: J4.8, U7.8 (R2IN)
/RS232, TTL/RTS_TTL: J3.3, Q4.3 (D), R19.1
/RS232, TTL/RX_IN: J4.3, U7.14 (T1OUT)
/RS232, TTL/RX_MAX: D3.1 (K), U7.12 (R1OUT)
/RS232, TTL/RX_TTL: D4.1 (K), J3.6
/RS232, TTL/TX_IN: J4.2, U7.13 (R1IN)
/RS232, TTL/TX_TTL: J3.5, Q2.3 (D), R16.1
/RS232, TTL/V+: C22.1, U7.2 (V+)
/RS232, TTL/V-: C19.1, U7.6 (V-)
/RS232, TTL/VTTL: J3.2, JP1.2, R16.2, R19.2
/RS232_RX: D3.2 (A), D4.2 (A), R18.1, U10.5 (2Y1)
/RS232_TX: Q1.2 (G), U7.11 (T1IN), U10.14 (1Y1)
/UMP_SW: JP2.1, R4.2, U2.9 (S)
/UT_D+: U2.1 (1D+), U13.5 (D+)
/UT_D-: U2.2 (1D-), U13.6 (D-)
/UT_RX: LD5.1 (K), U9.5 (2Y1), U13.3 (RxD)
/UT_TX: LD4.1 (K), U9.14 (1Y1), U13.2 (TxD)
/VDD_SDIO: C23.1, C40.1, U8.8 (VCC), U14.26 (VDD_SDIO)
GND: AE1.2 (Shield), C1.1, C2.2, C3.2, C4.2, C5.2, C6.2, C7.2, C8.2, C9.2, C10.2, C11.2, C12.2, C13.2, C14.2, C15.2, C16.2, C17.2, C18.2, C19.2, C23.2, C24.1, C25.1, C26.1, C28.2, C29.2, C30.2, C31.2, C32.2, C33.2, C34.2, C35.2, C36.2, C37.2, C38.2, C39.2, C40.2, C41.2, C42.2, C43.2, C44.2, C46.2, C47.2, J1.1 (GND), J1.12 (GND), J2.4 (GND), J3.1, J4.5, J5.G1 (GND_1), J5.G2 (GND_2), J5.G3 (GND_3), J5.P6 (VSS), J7.1, J10.1, J11.1, J12.2 (G_D2), J12.5 (G_D1), J12.8 (G_D0), J12.11 (G_CLK), J12.17 (G_DDC/CEC), J12.20 (SHIELD1), J12.21 (SHIELD2), J12.22 (SHIELD3), J12.23 (SHIELD4), JP2.6, LD1.1 (K), LD2.1 (K), LD3.1 (K), Q1.1 (S), Q2.1 (S), Q3.1 (S), Q4.1 (S), Q5.1 (S), R1.1, R2.1, R3.2, R7.2, R20.1, R21.1, R22.1, S2.2, S3.2, S4.2, U1.2 (GND), U2.5 (GND), U2.6 (~OE), U3.1 (GND), U4.2 (GND), U5.19 (TESTEN), U5.57 (GND), U6.4 (GND), U7.15 (GND), U8.4 (GND), U9.2 (2Y2), U9.4 (2Y3), U9.6 (~E), U9.7 (VEE), U9.8 (GND), U9.9 (S1), U9.11 (1Y3), U9.15 (1Y2), U10.2 (2Y2), U10.4 (2Y3), U10.6 (~E), U10.7 (VEE), U10.8 (GND), U10.9 (S1), U10.11 (1Y3), U10.15 (1Y2), U13.1 (GND), U14.49 (GND), Y1.2 (GND), Y2.2, Y2.4
unnamed: C47.1, L3.2, Y2.1
unnamed: D5.2 (A), Q5.3 (D), U11.2 (-)
unnamed: D6.2 (A), R28.2
unnamed: C28.1, D7.1 (K), J12.18 (+5V)
unnamed: J1.4 (CC1), R1.2
unnamed: J1.10 (CC2), R2.2
unnamed: J1.5 (DN2), J1.7 (DN1), R5.2
unnamed: J1.6 (DP1), J1.8 (DP2), R6.2
unnamed: J1.13 (SHIELD), R3.1
unnamed: J2.3 (D+), R8.2
unnamed: J2.2 (D-), R9.2
unnamed: J2.5 (Shield), R7.1
unnamed: J4.1, J4.4, J4.6
unnamed: J12.12 (CLKN), RN1.5 (R4.2)
unnamed: J12.10 (CLKP), RN1.6 (R3.2)
unnamed: J12.9 (D0N), RN1.7 (R2.2)
unnamed: J12.7 (D0P), RN1.8 (R1.2)
unnamed: J12.6 (D1N), RN2.5 (R4.2)
unnamed: J12.4 (D1P), RN2.6 (R3.2)
unnamed: J12.3 (D2N), RN2.7 (R2.2)
unnamed: J12.1 (D2P), RN2.8 (R1.2)
unnamed: LD1.2 (A), R13.1
unnamed: LD2.2 (A), R30.1
unnamed: LD3.2 (A), R29.2
unnamed: LD4.2 (A), R32.1
unnamed: LD5.2 (A), R33.2
unnamed: Q1.3 (D), Q2.2 (G), R14.1
unnamed: Q3.3 (D), Q4.2 (G), R17.1
unnamed: Q5.2 (G), R23.1
unnamed: R5.1, U1.1 (I/O1)
unnamed: R6.1, U1.3 (I/O2)
unnamed: R8.1, U4.1 (I/O1)
unnamed: R9.1, U4.3 (I/O2)
unnamed: R12.2, S2.1
unnamed: J1.2 (VBUS), J1.11 (VBUS), S1.2 (B)
unnamed: R11.2, U5.46 (USB_DM)
unnamed: R10.2, U5.47 (USB_DP)
unnamed: C5.1, C6.1, C7.1, U5.23 (DVDD), U5.45 (VREG_VOUT), U5.50 (DVDD)
unnamed: R35.1, U14.25 (GPIO16)
unnamed: R34.1, U14.41 (U0TXD)
VBUS: C2.1, C3.1, C22.2, C24.2, C25.2, D5.1 (K), D7.2 (A), J2.1 (VBUS), J11.2, JP1.1, JP2.4, JP2.5, S1.3 (A), U1.5 (VBUS), U3.3 (VI), U4.5 (VBUS), U7.16 (VCC), U9.16 (VCC), U10.16 (VCC), U11.1 (+)

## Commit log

2025-10-18 Routing WIP
    [protea32.kicad_pcb]
2025-10-19 Cleanup WIP
    [buzzer.kicad_sch, esp32-d0wd-v3.kicad_sch, esp32-flash.kicad_sch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]
2025-10-19 HW 1.00
    [protea32.kicad_pcb]
2025-11-08 HW 1.01
    [DS2401P+.stp, buzzer.kicad_sch, esp32-d0wd-v3.kicad_sch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]
2025-11-10 HW 1.01 Release
    [esp32-d0wd-v3.kicad_sch, protea32.kicad_pcb]
2025-11-10 HW 1.01 Release (fixed)
    [protea32.kicad_pcb]

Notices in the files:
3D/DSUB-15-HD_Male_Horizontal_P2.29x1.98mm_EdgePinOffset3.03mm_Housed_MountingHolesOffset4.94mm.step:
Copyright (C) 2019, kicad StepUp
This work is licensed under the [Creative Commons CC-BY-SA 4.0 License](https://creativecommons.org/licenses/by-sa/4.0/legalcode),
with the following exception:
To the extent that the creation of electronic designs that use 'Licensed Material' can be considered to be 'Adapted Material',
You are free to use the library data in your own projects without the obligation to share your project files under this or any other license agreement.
